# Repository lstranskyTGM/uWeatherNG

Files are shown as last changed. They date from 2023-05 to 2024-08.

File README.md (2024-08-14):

# uWeatherNG_Project

An ESP32-based weather monitoring system that collects environmental data from various sensors and publishes it to a MQTT broker topic. An agent subscribed to this topic receives the data and forwards it to an InfluxDB database. The data is then displayed on a website and visualized using Grafana dashboards.

## Background

This project was undertaken during the fourth year at TGM (Technologisches Gewerbemuseum Wien). We built upon the [project](https://github.com/lstranskyTGM/uWeather) developed in the third grade. Throughout the year, we documented our progress and presented the project's status to our teachers.

## Overview

### ESP32
- Main controller for the weather monitoring system
- Reads sensor data
- Sends data to database
- Enters DeepSleep for configured time
- Wakes up and repeats

### MQTT Broker
- Receives data from ESP32

### Telegraf
- Collects data from MQTT Broker
- Sends data to InfluxDB

### InfluxDB
- Stores data from ESP32

### Website
- Displays data from database
- Shows ESP32 location on Google Maps

### Grafana
- Visualizes data from database

### Cloudflared (Optional)

- Securely exposes local server to the internet

## Documentations

- [DockerCompose](https://github.com/lstranskyTGM/uWeatherNG/tree/main/DockerCompose)
- [ESP32](https://github.com/lstranskyTGM/uWeatherNG/tree/main/ESP32)
- [Hardware](https://github.com/lstranskyTGM/uWeatherNG/tree/main/Hardware)
- [Website](https://github.com/lstranskyTGM/uWeatherNG/tree/main/Website)

## Development

(In Progress)

## Implemented Functions

- [x] Swithed to LTE instead of WiFi
- [x] Added an Anemometer to measure wind speed
- [x] Added a Wind Vane to measure wind direction
- [x] Added an Air Quality Sensor to measure air quality
- [x] Implemented Grafana to display data from the database
- [x] Used the MQTT protocol for data transmission
- [x] Replaced the MySQL database with a InfluxDB database

## Unimplemented Functions

- [ ] Micro SD Card Reader Module (hardware implemented, code not written)

## Implemented Functions

## Possible Extensions

- [ ] Switch to LoRaWAN for extended range and cost-effective data transfer
- [ ] Add a Rain Gauge to measure rainfall
- [ ] Disable unused digital pins to conserve power when not needed
- [ ] Develop a custom PCB for the ESP32 and all sensors
- [ ] Replace the ESP32 Dev Module with a more compact and efficient ESP32 board
- [ ] Implement ESPHome / Home Assistant

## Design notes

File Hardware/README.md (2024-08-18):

# Hardware Box

<p align="center">
    
</p>

## Overview

The uWeatherNG project’s hardware components were designed using Fusion 360 and 3D printed with an Original Prusa i3 MK3S+ printer.

This system is modular and easy to set up, consisting of several key components:

**Main Parts:**

- **Main Box:** This is the heart of the system, containing the ESP32 microcontroller, OLED display, LTE and GPS modules, SD card reader, and a power bank. It handles all the data processing and transmission.

- **Sensor Box:** This box holds all the environmental sensors, keeping them safe while they collect weather data.

- **Cable Box:** A dedicated space for organizing and storing all the cables, keeping the setup tidy.

- **Anemometer and Wind Vane:** These tools measure wind speed and direction, which are key parts of weather monitoring.

- **Antenna Mount:** This part holds the antenna in place, ensuring good signal strength for data communication.

The system is built using connectors and aluminum tubes, which make it easy to assemble and disassemble, allowing for quick deployment in different locations.

**Material and Durability:** The prototype is printed with PETG filament, which is waterproof, UV-resistant, and weatherproof, making it durable for outdoor use.

**Additional Features:**

- **Air Vents:** These vents are included to allow proper airflow around the sensors, ensuring they measure accurate environmental conditions without being influenced by any potential heat build-up inside the enclosure.
  
- **Plexiglass Covers:** These protect the sensors and modules from rain, while still allowing them to function properly.
  
- **Dupont Connectors:** These are used for all the cable connections, making the setup easy to put together and take apart.

Overall, the uWeatherNG system is designed to be strong, reliable, and able to withstand different weather conditions, making it perfect for ongoing weather monitoring.

## Other Images

<table>
  <tr>
    <td align="center">
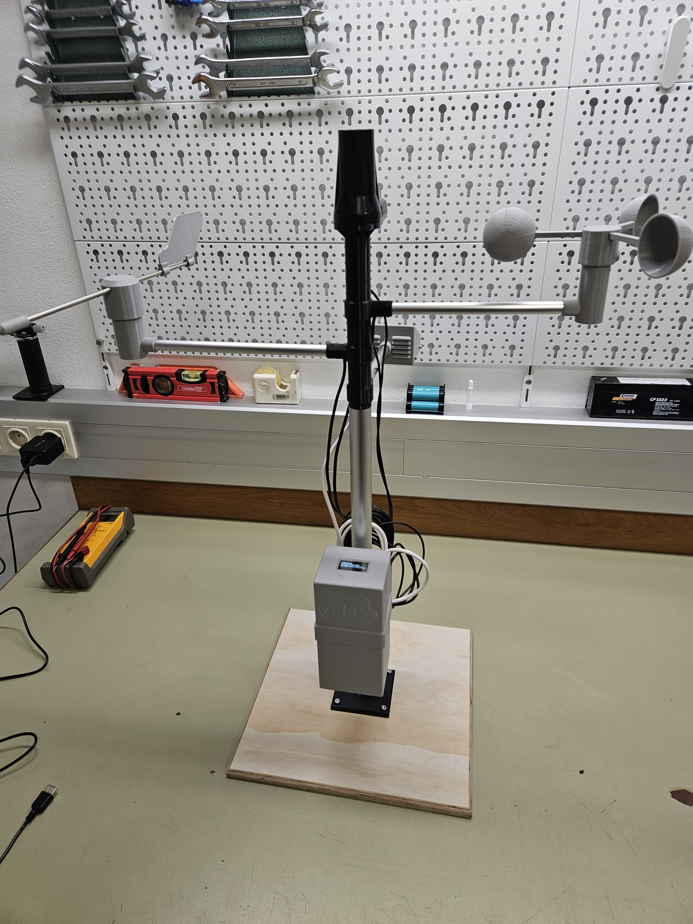
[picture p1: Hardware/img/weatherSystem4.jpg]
      
    </td>
    <td align="center">
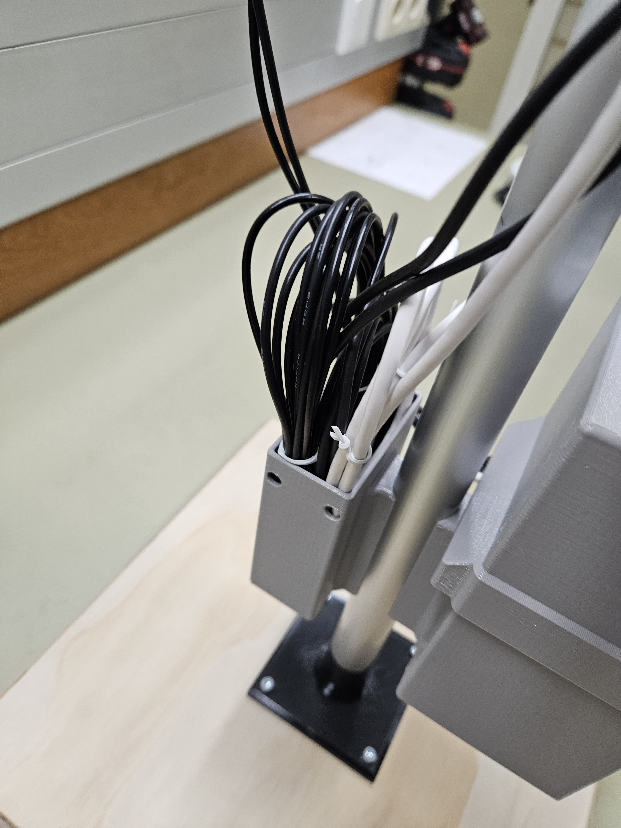
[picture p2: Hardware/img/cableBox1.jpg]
      
    </td>
    <td align="center">
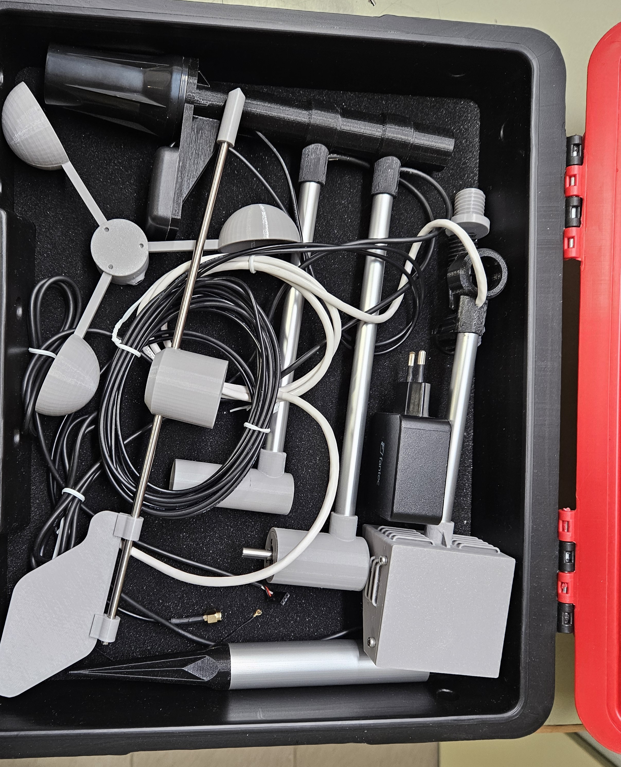
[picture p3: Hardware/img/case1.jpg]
      
    </td>
  </tr>
  <tr>
    <td align="center">
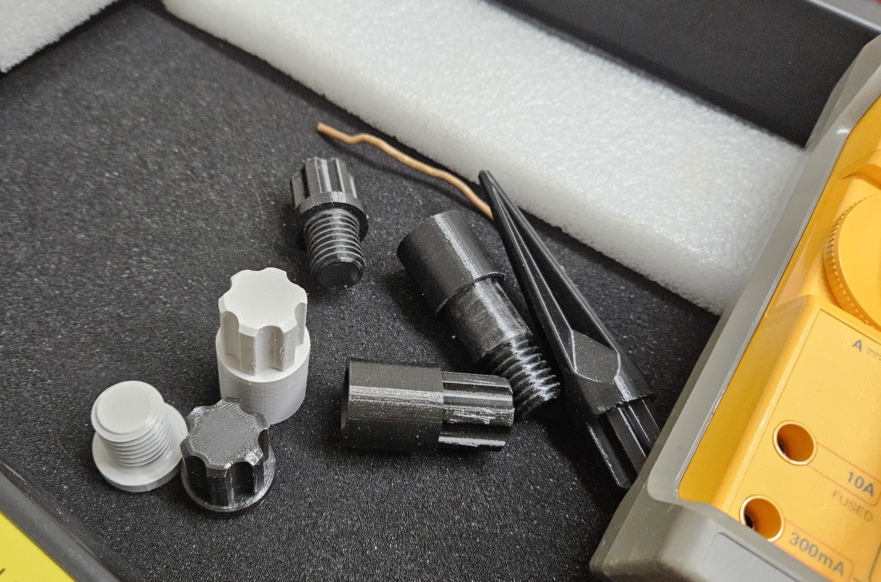
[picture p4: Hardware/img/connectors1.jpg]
      
    </td>
    <td align="center">
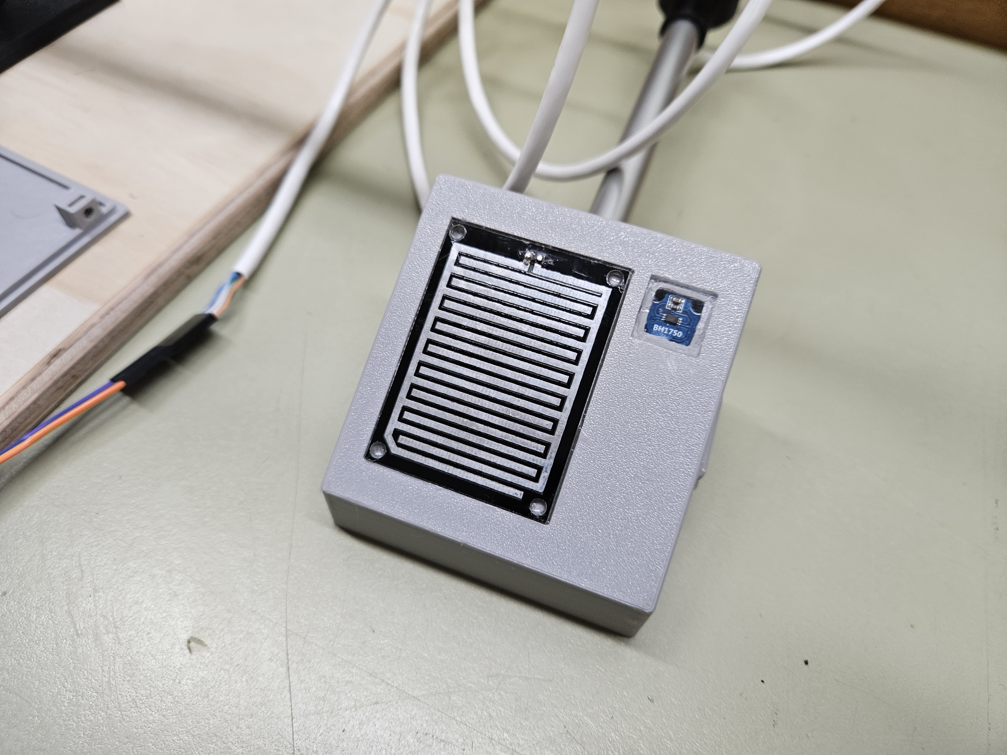
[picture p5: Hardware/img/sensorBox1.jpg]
      
    </td>
    <td align="center">
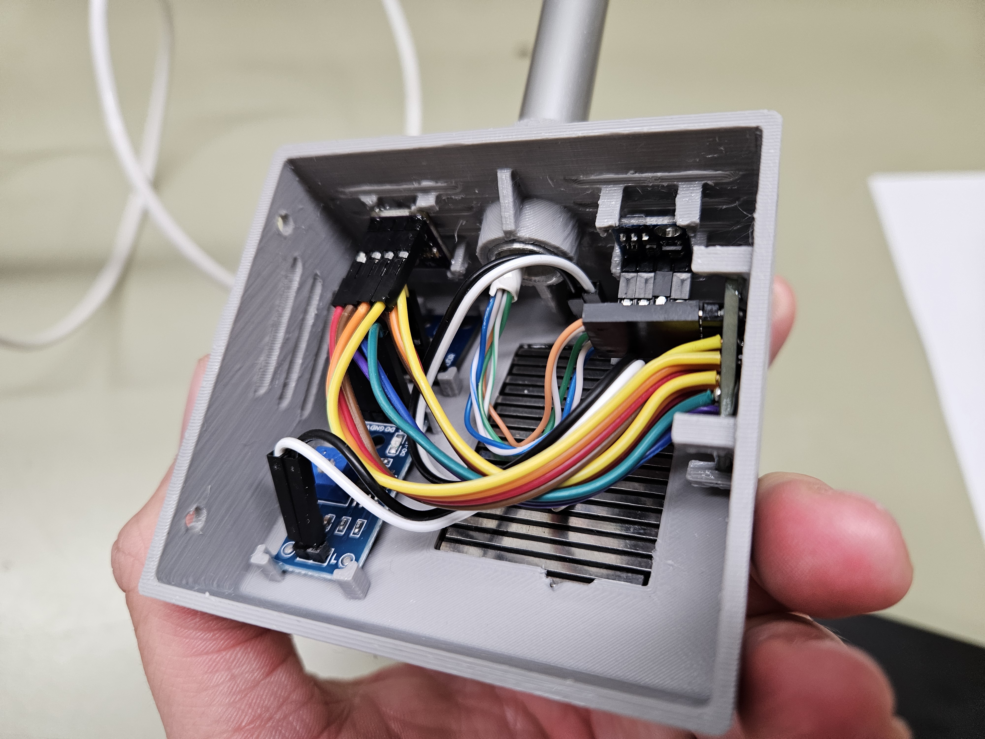
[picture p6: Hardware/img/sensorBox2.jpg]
      
    </td>
  </tr>
  <tr>
    <td align="center" colspan="3">
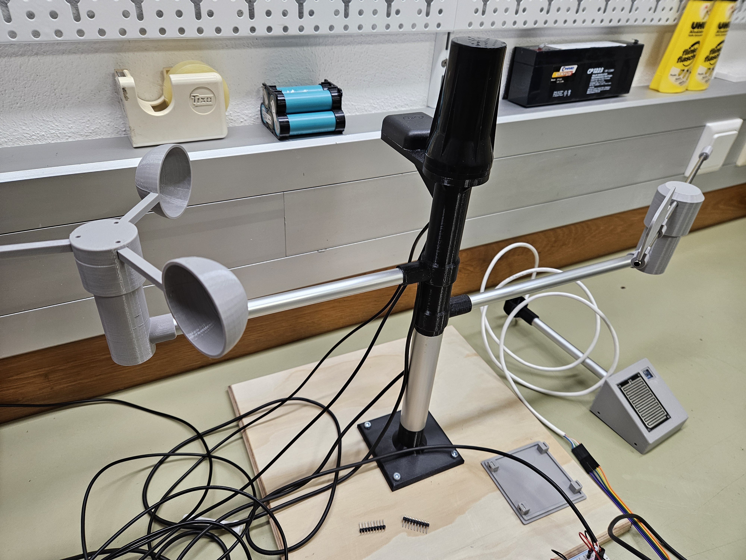
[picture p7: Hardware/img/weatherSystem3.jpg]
      
    </td>
  </tr>
</table>

## External Resources

For the anemometer and wind vane used in this project, I utilized existing models available on Thingiverse, with some modifications to better suit the needs of this project. You can find the original models I used and modified here:

- **Anemometer:** [Thingiverse Link](https://www.thingiverse.com/thing:2559929/files)
- **Wind Vane:** [Thingiverse Link](https://www.thingiverse.com/thing:4757278/files)

## ToDo

- [x] ~~Modular System~~
- [x] ~~Water resistant~~
- [x] ~~uWeather Logo~~
- [x] ~~Larger Display~~

## Possible Extensions

- [ ] Seal Connections between the parts
- [ ] MainBox Angled Top for better rain runoff

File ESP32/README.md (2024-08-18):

# ESP32

## Test Scripts

In the test scripts all functions for the ESP32 are tested seperately. This makes it easier to find errors and debug everything.   

## Main Script

<p align="center">
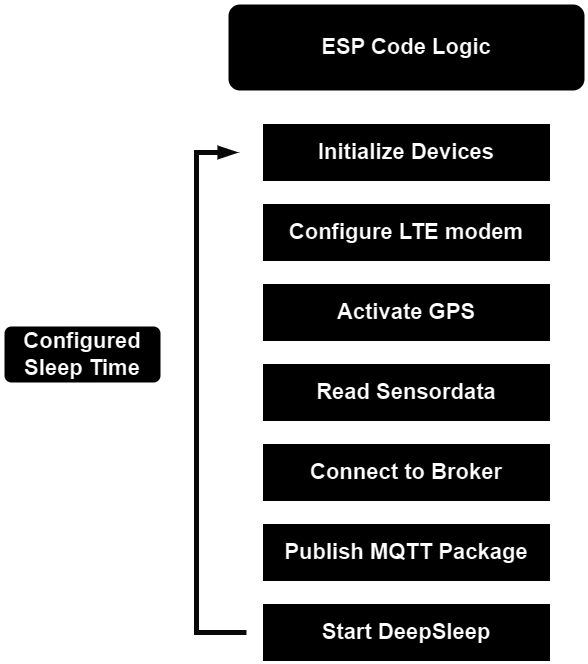
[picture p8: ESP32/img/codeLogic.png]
codeLogic
    
</p>

The ESP32 script initiates by setting up various sensors and modules, including GPS, and collecting environmental data. It then attempts to transmit this information via MQTT over an LTE connection. If the connection is established, the collected data is published to a designated topic on an MQTT broker. After transmission, the ESP32 enters a deep sleep mode to conserve energy, periodically waking to update and resend data. Throughout this process, all status updates and messages are displayed both on the Serial Monitor and an OLED display. This configuration ensures continuous, efficient monitoring of environmental conditions with minimal human intervention.

## Sensor / Module List

### GY-302 BH1750 Light Sensor Module

The GY-302 BH1750 Photoresistor module is used to measure light intensity. The resistance will decrease in the presence of light and increase in the absence of it. 

**Light Intensity:** lux

[Buy here](https://www.az-delivery.com/products/gy-302-bh1750-lichtsensor-lichtstaerke-modul-fuer-arduino-und-raspberry-pi)

### GY-BME280 Environmental Sensor [I2C]

This sensor measures relative humidity, barometric pressure, and ambient temperature, communicating via the I2C bus.

**Relative Humidity:** %RH

**Barometric Pressure:** hPa

**Ambient Temperature:** °C

[Buy here](https://www.bosch-sensortec.com/products/environmental-sensors/humidity-sensors-bme280/)

### FC-37 Rain Sensor Module

The FC-37 module detects rain, with lower resistance signaling rain presence and triggering a high output signal.

**Rain:** True/False

[Buy here](https://www.az-delivery.com/en/products/regen-sensor-modul)

### GY-SGP30 Air Quality Sensor [I2C]

THe GY-SGP30 is a digital air quality sensor that measures the amount of volatile organic compounds (VOCs) in the air. The sensor also measures the equivalent carbon-dioxide (eCO2) concentration.
It uses the I2C bus to communicate with the ESP32.

**Total Volatile Organic Compounds (TVOC):** ppb

**Equivalent Carbon-dioxide (eCO2):** ppm

[Buy here](https://funduinoshop.com/elektronische-module/sensoren/gase/gy-sgp30-tvoc-sensor-fuer-luftqualitaet-eco2)

### KY-003 Digital Hall Effect Sensor (Anemometer)

This sensor detects the magnetic field of a spinning magnet attached to an anemometer to calculate wind speed.

**Wind Speed:** km/h

[Buy here](https://www.az-delivery.com/en/products/hall-sensor-modul-digital)

### Rotary Hall Angle Sensor (Wind Vane)

The rotary hall angle sensor is used to measure the angle of the wind vane.

**Wind Direction:** Degrees (°)

[Buy here](https://www.aliexpress.com/item/4000143910873.html?gatewayAdapt=glo2deu)

### 1.3 inch OLED Display [I2C]

This OLED display shows the status and data collected by the ESP32, utilizing the I2C bus for communication.

[Buy here](https://www.az-delivery.de/en/products/1-3zoll-i2c-oled-display)

### Micro SD Card Reader Module

The micro SD card reader module is used to configure the Main Script.

[Buy here](https://www.az-delivery.de/en/products/copy-of-spi-reader-micro-speicherkartenmodul-fur-arduino)

### SIM7000E NB-IoT Module

The SIM7000E NB-IoT Module is used to connect the ESP32 to the internet, sending the data to a MQTT broker.
It also has a GPS module that can be used to get the current location of the ESP32.

**Latitude:** Degrees (°)

**Longitude:** Degrees (°)

**Altitude:** Meters (m)

[Buy here](https://www.waveshare.com/sim7000e-nb-iot-hat.htm)

## ToDo List

- [x] ~~Write all test scripts~~
- [x] ~~Write the main script~~

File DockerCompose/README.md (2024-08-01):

# DockerCompose

This system offers a ready-to-deploy solution that runs seamlessly across different environments supporting Docker and Docker Compose. It effectively orchestrates all containers, ensuring consistent performance and reliability. The setup boosts portability, scalability, and maintainability, ideal for demanding operational environments.

## Setup

1. Ensure Docker and Docker Compose are installed on your system.
2. Clone the repository to your local machine.
3. Navigate to the `DockerCompose` directory.
4. Configure the docker-compose.yml file to suit your environment.
5. Run the following command to start the system:

```bash
docker-compose up -d
```

6. Create Tokens for Grafana and Telegraf
7. Update the Telegraf configuration file with the InfluxDB token
8. Configure Grafana to connect to InfluxDB

## Configuration

### Docker Compose

Set credentials and environment variables in the `docker-compose.yml` file.

### Cloudflared (Optional)

Configure the tunnel `your-tunnel-id.json` and `config.yml` files.

### Mosquitto (Optional)

Configure the `mosquitto.conf` file with the desired settings.

### Telegraf

Configure the `telegraf.conf` file with the InfluxDB token.
If you are using the external MQTT broker change the broker address.
Change any other settings as needed. 

## Structure

The system includes the following components:

- **Cloudflared: (Optional)** A tunneling service that securely exposes the local server to the internet.
- **Mosquitto: (Optional)** An MQTT broker that enables real-time communication between IoT devices.
- **Telegraf:** A plugin-driven server agent for collecting and reporting metrics.
- **InfluxDB:** A time-series database that stores data points.
- **Grafana:** A visualization tool that creates dashboards for monitoring and analyzing data.
- **httpd:** A web server that provides access to a web page.

## Data Flow

The ESP32 device collects environmental data from various sensors and transmits it to the MQTT broker using the MQTT protocol. The data is then forwarded to the Telegraf agent, which processes and sends it to the InfluxDB database for storage. Grafana connects to the database to retrieve the data points and displays them on a dashboard for monitoring and analysis. Users can access the dashboard or a web page hosted by the httpd server to viev the real-time data.

## Line Protocol

The Line Protocol is a text-based format for writing data points to the InfluxDB database. It consists of a series of fields and tags that define the structure of the data points. The Line Protocol is used to insert, update, and delete data points in the database, enabling efficient storage and retrieval of time-series data.

### Format

````plaintext
<measurement>[,<tag-key>=<tag-value>,...] [<field-key>=<field-value>,...] [<timestamp>]
````

### Example 

```plaintext
# With Timestamp
weather,location=Vienna temperature=25,humidity=50,pressure=1013 1626825600000000000

# Without Timestamp
weather,location=Vienna temperature=25,humidity=50,pressure=1013
```

## Possible Extensions

- [ ] Add dashboard data for grafana

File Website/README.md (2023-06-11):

# Website

## Logo:

<p align="center">
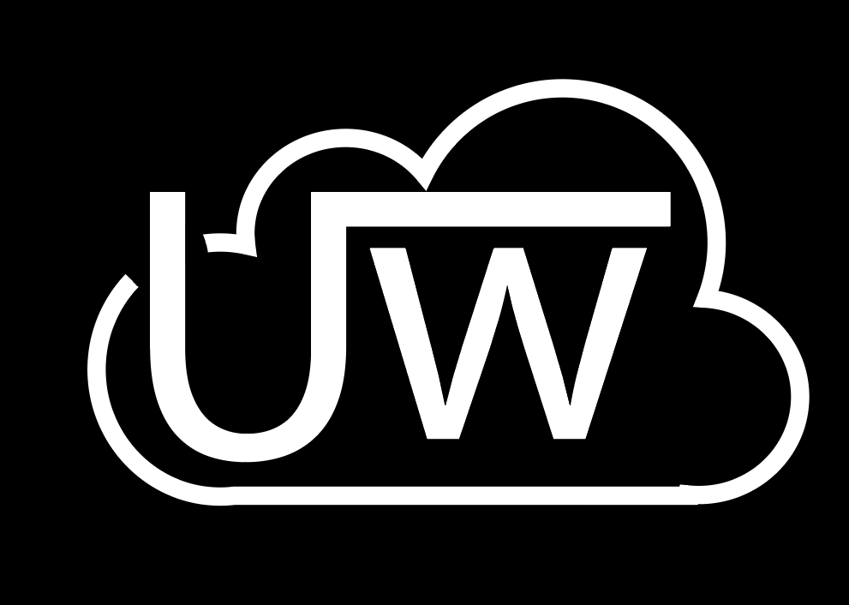
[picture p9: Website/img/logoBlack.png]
uWeather_Logo
    
</p>

## Mockup:

<p align="center">
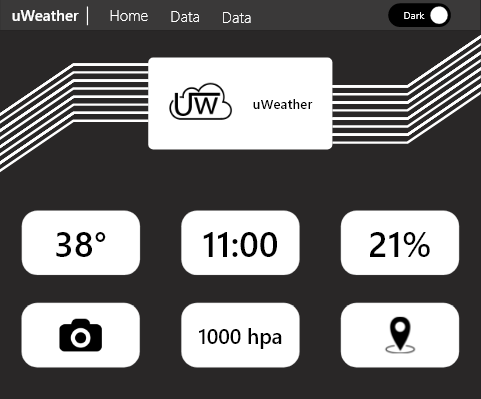
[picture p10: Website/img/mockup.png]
website_Mockup
    
</p>

The current Website displays all the sensor Data from the ESP32 and the time when the data was updated. Google Maps also shows the exact location of the ESP32 (20-30 meters inaccuracy). Animations are used to make the website more appealing. 

For an White/Dark Mode was not enough time.
The values presented on the website are only placeholders, because NodeJs/VueJs was not implemented yet.  

# ToDo List:

- [x] ~~Create a Mockup~~
- [x] ~~Create a Logo~~
- [x] ~~Create a basic html Website~~
- [x] ~~Implement css (Bootstrap)~~
- [x] ~~Implement Animations~~
- [x] ~~Implement Connection to Database~~
- [x] ~~Implement Google Maps~~
- [x] ~~Implement Bootstrap~~
- [ ] Implement White/Dark Mode
- [ ] Implement NodeJs/VueJs to Update Sensor Data

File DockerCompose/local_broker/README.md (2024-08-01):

# local_broker

This Docker Compose configuration includes a local MQTT broker, creating a self-contained system for data exchange. This setup is best suited for standalone deployments or when data sovereignty and network independence are priorities.

## Cloudflared (Optional)

This optional tunneling service securely exposes your local server to the internet via the Cloudflare network, enhancing data privacy and integrity. It can be disabled for closed-network environments to streamline operations.

## Mosquitto (Optional)

An efficient, lightweight MQTT broker that enables real-time communication between IoT devices. It is particularly useful in localized networks or for testing purposes and can be disabled if not needed.

## Telegraf

A plugin-driven server agent that collects metrics from diverse sources including system metrics, logs, and sensors. Data is forwarded to InfluxDB for detailed analysis, optimized for scalability and flexibility in data handling.

## InfluxDB

A specialized time-series database that excels in storing and retrieving structured data points efficiently. It supports complex queries and real-time analytics, making it perfect for high-velocity data environments.

## Grafana

A powerful visualization tool that creates intuitive dashboards from data stored in InfluxDB. It helps monitor system performance and identify trends, aiding in decision-making and operational oversight.

## httpd

This web server component acts as the front end, offering real-time interaction and visualization of the data through a user-friendly web interface.

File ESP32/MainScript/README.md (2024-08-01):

# MainScript

# ToDo List

- [x] ~~Implement SGP30 Sensor~~
- [x] ~~Implement Anemometer~~
- [x] ~~Implement Wind Vane~~
- [x] ~~Implement LTE Modem~~
- [x] ~~Implement MQTT Client~~
- [x] ~~Implement Read GNSS~~
- [ ] Implement Micro SD Card Reader
  
## Possible Extensions

- [ ] Implement `millis()` instead of `delay()`
- [ ] Implement startup delay to allow sensors to warm up
- [ ] Optimize power usage by controlling digital pins
- [ ] Implement local storage for data
- [ ] Implement logging file for errors
- [ ] Implement configuration file for settings

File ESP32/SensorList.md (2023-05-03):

# Sensor List:

## KY0-18:  gemacht

The KY-018 Photoresistor module is used to measure light intensity. The resistance will decrease in the presence of light and increase in the absence of it. The output is analog and determines the intensity of light.

Light intensity: lux

Link:
https://arduinomodules.info/ky-018-photoresistor-module/

## BME280: gemacht

Humidity sensor measuring relative humidity, barometric pressure and ambient temperature

Relative humidity: %

Barometric pressure: hPa

Ambient temperature: m

Link:
https://www.bosch-sensortec.com/products/environmental-sensors/humidity-sensors-bme280/

##  Raindrop Rain Sensor Module   gemacht

Raindrop Rain Sensor Module is a module used to detect and measure rain. It usually consists of a sensor that can detect the presence of water droplets, and an electronic circuit that can process the signal from the sensor and output an indication of whether it is raining or not. 

Rain: (true/false)

Link:
https://www.az-delivery.de/en/products/regen-sensor-modul

##  NEO-6M GPS Module: gemacht

GPS Sensor

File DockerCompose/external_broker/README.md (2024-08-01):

# external_broker

This Docker Compose configuration is designed for integration with an external MQTT broker, facilitating seamless data exchange with existing infrastructures and services. This setup is ideal for environments where centralized control over multiple deployments is needed.

## Cloudflared (Optional)

This optional tunneling service securely exposes your local server to the internet via the Cloudflare network, enhancing data privacy and integrity. It can be disabled for closed-network environments to streamline operations.

## Telegraf

A plugin-driven server agent that collects metrics from diverse sources including system metrics, logs, and sensors. Data is forwarded to InfluxDB for detailed analysis, optimized for scalability and flexibility in data handling.

## InfluxDB

A specialized time-series database that excels in storing and retrieving structured data points efficiently. It supports complex queries and real-time analytics, making it perfect for high-velocity data environments.

## Grafana

A powerful visualization tool that creates intuitive dashboards from data stored in InfluxDB. It helps monitor system performance and identify trends, aiding in decision-making and operational oversight.

## httpd

This web server component acts as the front end, offering real-time interaction and visualization of the data through a user-friendly web interface.

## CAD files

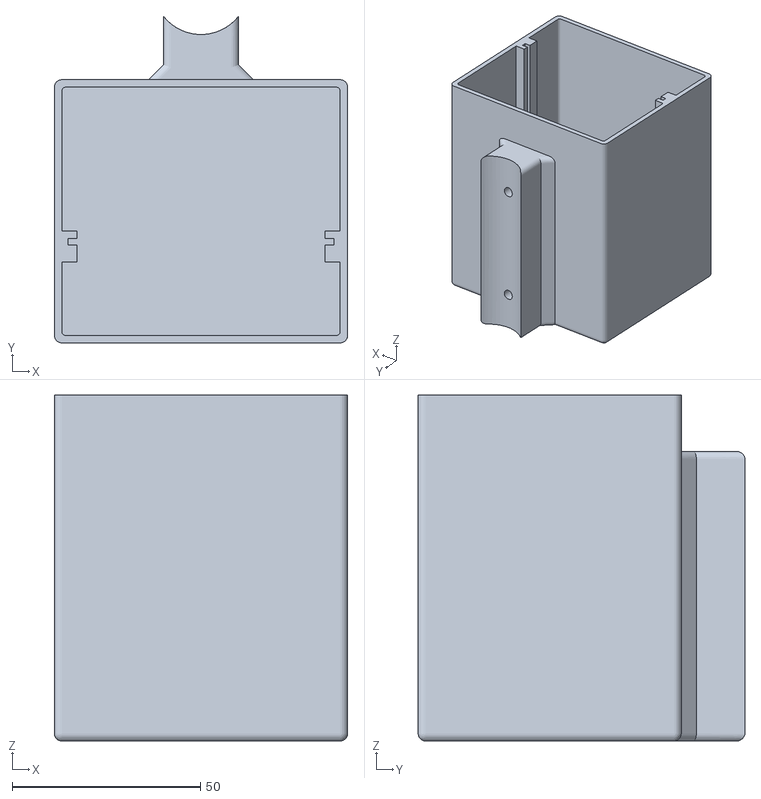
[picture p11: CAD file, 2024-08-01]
Hardware/MainBox/MainBox_Bottom.stl
78.0 x 86.9 x 92.0

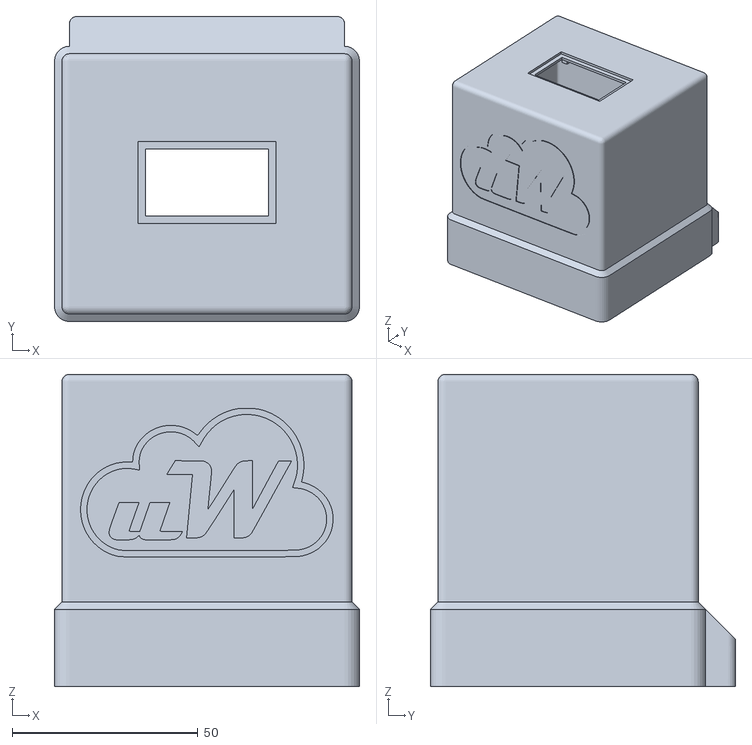
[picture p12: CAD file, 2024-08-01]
Hardware/MainBox/MainBox_Top.stl
82.0 x 82.0 x 84.0

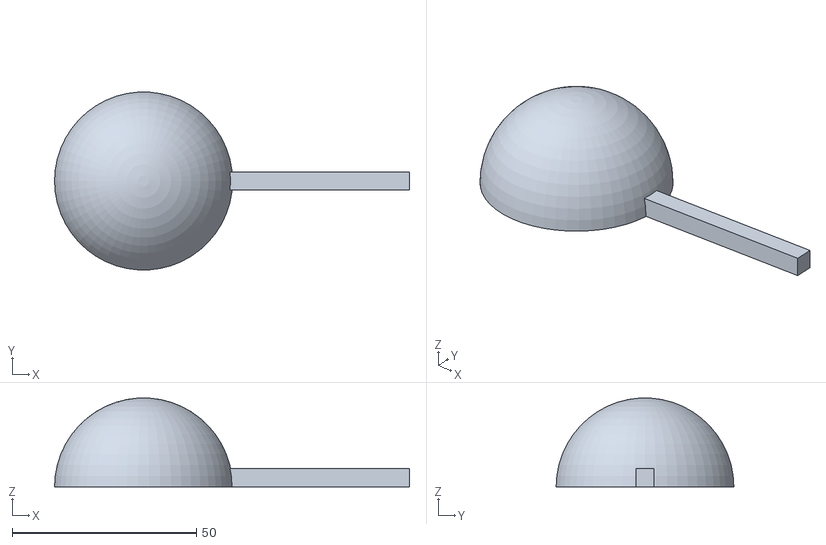
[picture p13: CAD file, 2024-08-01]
Hardware/Anemometer/Anemometer_Cup.stl
96.3 x 48.2 x 24.1

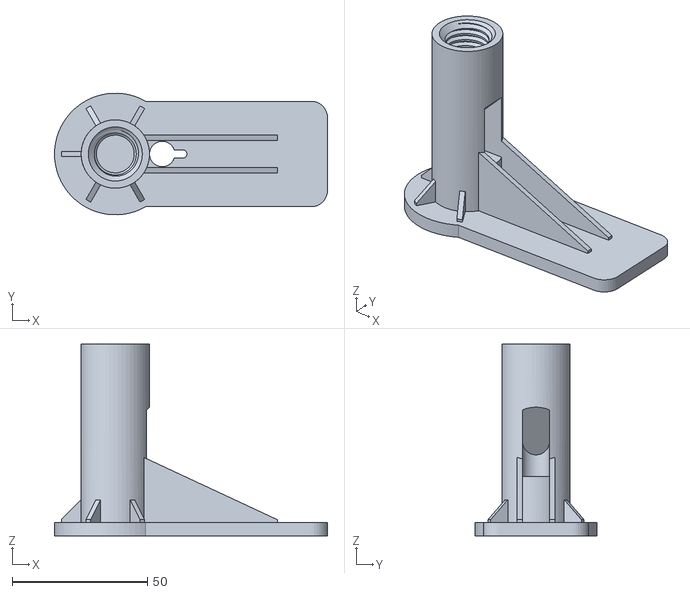
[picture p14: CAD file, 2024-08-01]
Hardware/Antenna/AntennaHolder_InternalThread.stl
101.0 x 45.0 x 71.0

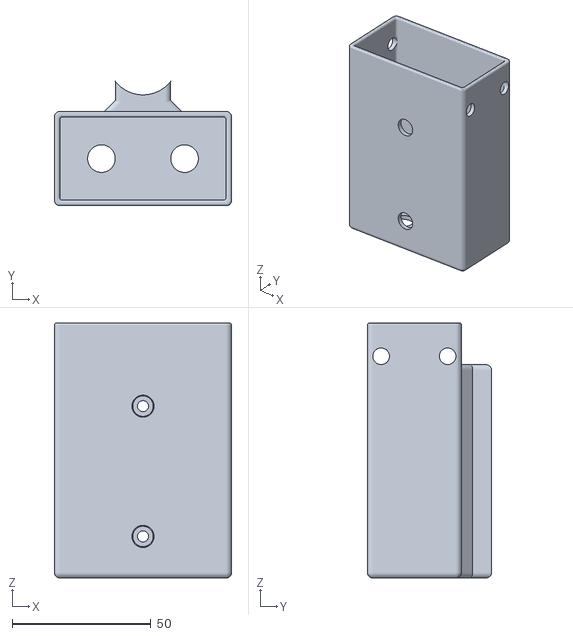
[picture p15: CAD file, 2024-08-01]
Hardware/CableManagement/CableBox.stl
64.0 x 44.9 x 92.0

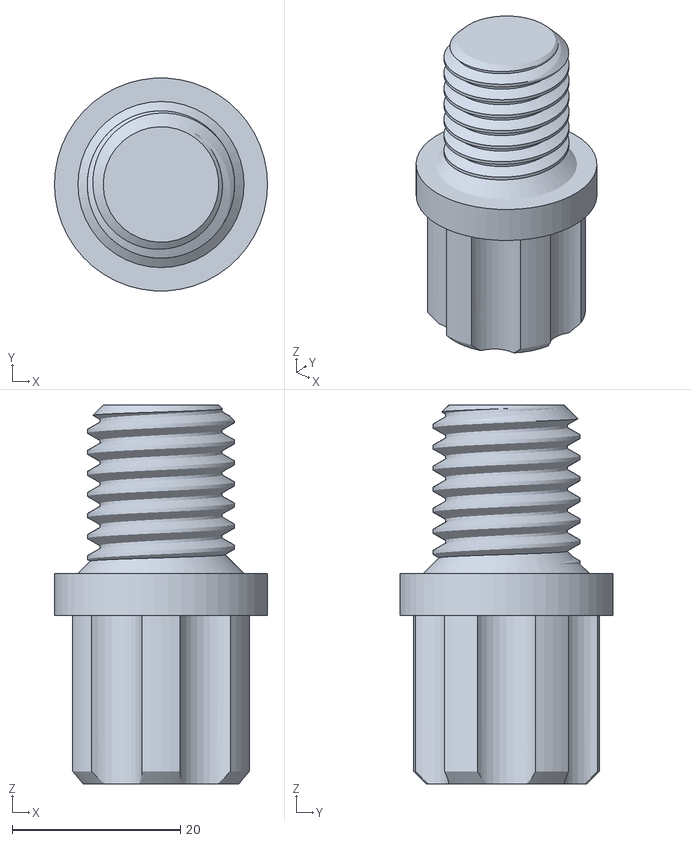
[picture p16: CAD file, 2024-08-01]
Hardware/Connectors/Plug_ExternalThread.stl
25.3 x 25.3 x 45.0

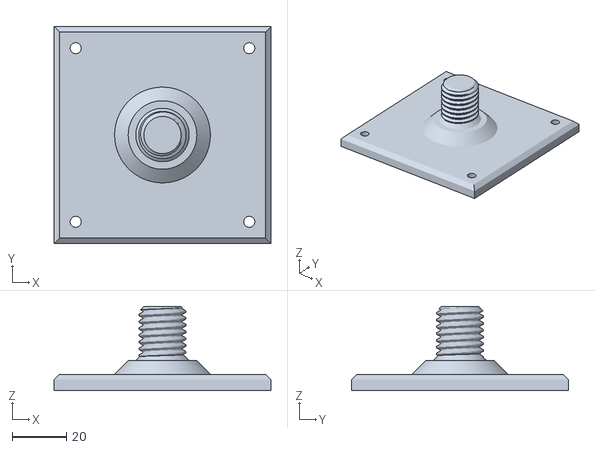
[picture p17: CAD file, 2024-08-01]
Hardware/MountingPlates/Plate_ExternalThread.stl
80.0 x 80.0 x 31.0

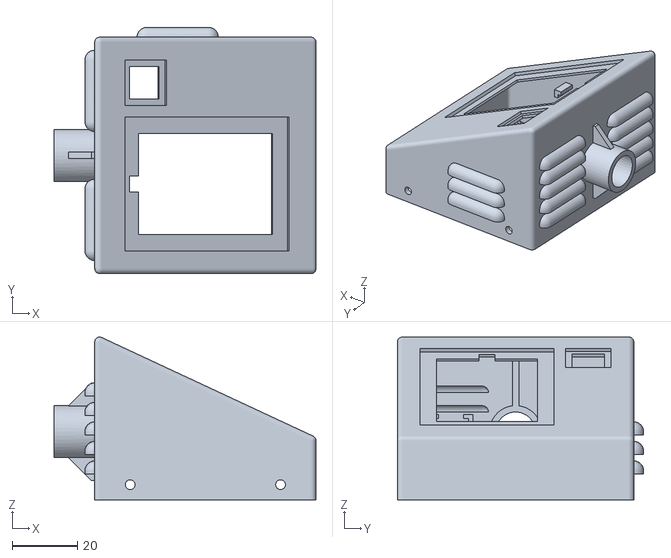
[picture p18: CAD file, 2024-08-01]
Hardware/SensorBox/SensorBox_Top.stl
80.5 x 75.6 x 50.1

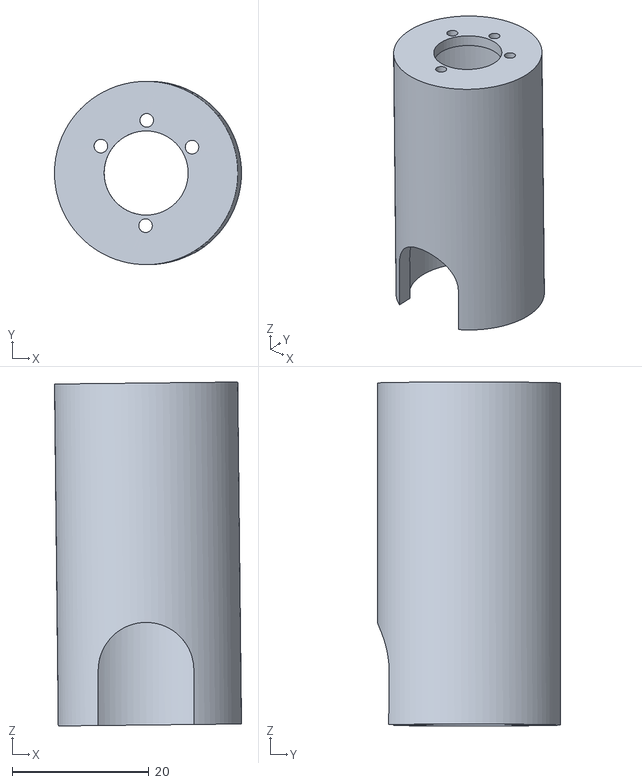
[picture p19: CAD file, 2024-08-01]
Hardware/Vane/Vane_Middle.stl
27.4 x 26.8 x 50.3

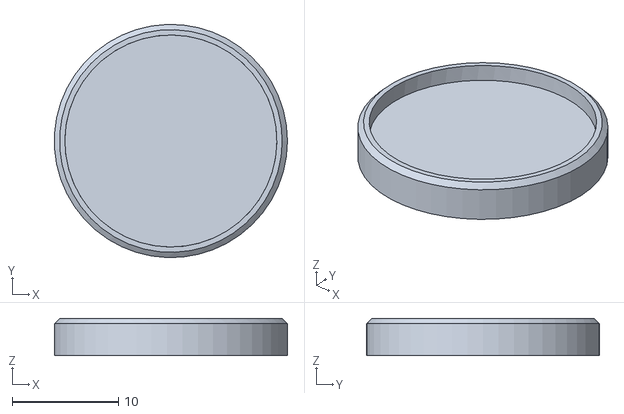
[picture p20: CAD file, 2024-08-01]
Hardware/Anemometer/Anemometer_Cap.stl
22.0 x 22.0 x 3.50

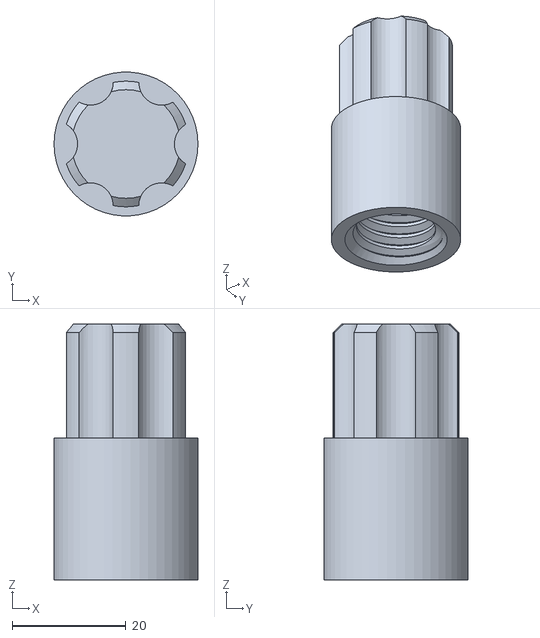
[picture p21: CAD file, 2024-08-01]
Hardware/Connectors/Plug_InternalThread.stl
25.3 x 25.3 x 45.0

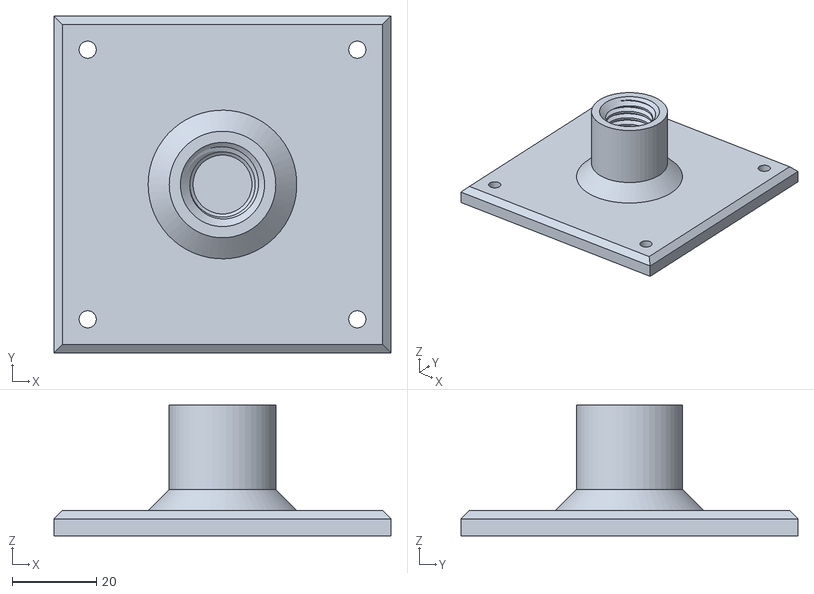
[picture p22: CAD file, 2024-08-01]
Hardware/MountingPlates/Plate_InternalThread.stl
80.0 x 80.0 x 31.0

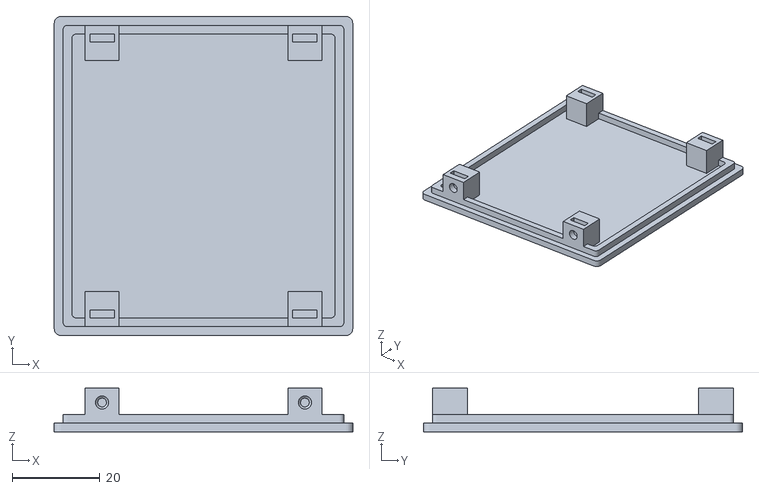
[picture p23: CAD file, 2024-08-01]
Hardware/SensorBox/SensorBox_Bottom.stl
68.0 x 72.6 x 10.0

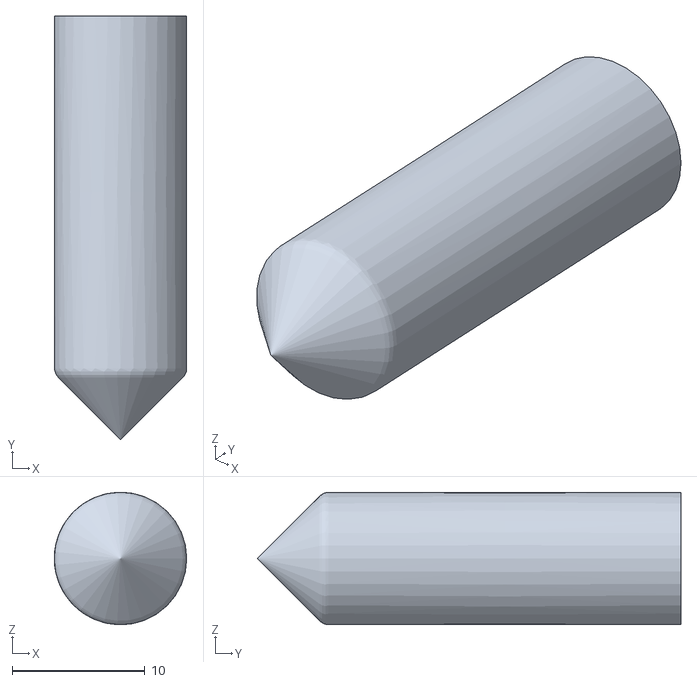
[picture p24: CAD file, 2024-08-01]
Hardware/Vane/Vane_Tip.stl
10.0 x 32.0 x 10.0

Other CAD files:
Hardware/Anemometer/Anemometer_Top.stl
Hardware/Connectors/Plug_Joint_ExternalThread.stl
Hardware/Vane/Vane_Fin.stl
Hardware/Anemometer/Anemometer_Body.stl
Hardware/Connectors/Joint.stl
Hardware/Connectors/Joint_InternalThread_ExternalThread.stl
Hardware/Connectors/Plug_Spike.stl
Hardware/Vane/Vane_Bottom.stl
Hardware/Vane/Vane_Fin_Mount.stl
Hardware/Vane/Vane_Top.stl

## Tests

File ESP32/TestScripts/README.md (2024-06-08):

# Testscripts

# ToDo List

- [x] ~~Buy Sensors~~
- [x] ~~Write scripts~~
- [x] ~~Check for errors~~

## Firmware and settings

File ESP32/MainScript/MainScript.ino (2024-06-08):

/*
 * Projekt: uWeather Datalogging System
 * Description: Utilizes ESP32 to measure environmental data with various sensors, transmitting results via MQTT. 
 * Optimized for low-power consumption with automated deep sleep cycles.
 * Author: Leonhard Stransky
 * Creation Date: 2023.05.07
 */

// Libraries
#include <time.h>                       // Standard C library for time-related functions
#include <Wire.h>                       // Wire Library for I2C communication, part of the Arduino core
#include <BH1750.h>                     // Ambient light sensor library, source: https://github.com/claws/BH1750
#include <Adafruit_Sensor.h>            // Adafruit Unified Sensor Driver, source: https://github.com/adafruit/Adafruit_Sensor
#include <Adafruit_BME280.h>            // Adafruit library for BME280 sensors, source: https://github.com/adafruit/Adafruit_BME280_Library
#include <Adafruit_SGP30.h>             // Adafruit library for the SGP30 gas sensor, source: https://github.com/adafruit/Adafruit_SGP30
#include <Adafruit_GFX.h>               // Base library for Adafruit’s display drivers, source: https://github.com/adafruit/Adafruit-GFX-Library
#include <Adafruit_SH110X.h>            // Adafruit library for SH110x Monochrome OLED/LED Displays, source: https://github.com/adafruit/Adafruit_SH110X
#include <HardwareSerial.h>             // Provides Serial communication functionality on ESP32
#include <BotleticsSIM7000.h>           // Botletics SIM7000 LTE module library, source: https://github.com/botletics/SIM7000-LTE-Shield

// LTE modem details
#define SIMCOM_7000     // LTE Module Chip
#define TX 16           // ESP32 hardware serial RX2 (GPIO16)
#define RX 17           // ESP32 hardware serial TX2 (GPIO17)

// MQTT Broker details
#define MQTT_SERVER      "mqtt.broker.net"      // The address of the MQTT broker server
// Common MQTT Ports:
// 1883: Default unencrypted port
// 8883: Default encrypted port (TLS/SSL)
// 1884: MQTT over WebSockets (unencrypted)
// 8884: MQTT over WebSockets (encrypted)
#define MQTT_PORT        1883                   // The port of the MQTT broker server
#define MQTT_USERNAME    "YourMQTTUsername"     // Optional: Username for MQTT broker authentication, if required
#define MQTT_PASSWORD    "YourMQTTPassword"     // Optional: Password for MQTT broker authentication, if required
#define MQTT_CLIENTID    "YourClientID"         // Optional: A unique client identifier used to identify the device to the broker

// Other Settings

// Boolean flag indicating whether MQTT messages should be retained on the broker
// Retain messages are stored on the broker and sent to new subscribers when they subscribe to a topic
// If set to 0 (false), messages are not retained, not stored on the broker after delivery
// If set to 1 (true), messages are retained, stored on the broker and sends them to new subscribers
const bool retain_messages = 0;

// Quality of Service (QoS) level for MQTT messages
// QoS 0: The broker/client will deliver the message once, with no confirmation
// QoS 1: The broker/client will deliver the message at least once, with confirmation required
// QoS 2: The broker/client will deliver the message exactly once by using a four-step handshake
// This setting specifies a QoS level of 2, ensuring that messages are delivered exactly once
const int qos_level = 2;

// MQTT Topics
// Topic under which sensor data will be published.
const char* topicSensors = "sensors/";

// For ESP32 hardware serial
HardwareSerial modemSS(1);                            // Instance of the HardwareSerial class to manage serial communication
Botletics_modem_LTE modem = Botletics_modem_LTE();    // Instance of the LTE modem class

// Declarations for DeepSleep
#define uS_TO_S_FACTOR 1000000ULL   // Conversion factor for micro seconds to seconds
#define TIME_TO_SLEEP 5 * 60        // Time ESP32 will go to sleep (in seconds)

// Variables that get saved during DeepSleep
RTC_DATA_ATTR int bootCount = 0;                  // Counts the number of boots since last power cycle
//RTC_DATA_ATTR boolean requestedNTP;               // If NTP Server was already requested
RTC_DATA_ATTR boolean bIsRaining = false;         // Last Known Rain Value for next boot (Inital state not raining)

// Declarations for Display
#define SCREEN_WIDTH 128        // OLED display width in pixels
#define SCREEN_HEIGHT 64        // OLED display height in pixels
#define OLED_RESET     -1       // Reset pin for the OLED Display (-1 if not used)
//#define SCREEN_ADDRESS 0x3c     // Address 0x3D for 128x64
#define WHITE 1                 // Color definition for drawing text and graphics on the display
Adafruit_SH1106G display = Adafruit_SH1106G(SCREEN_WIDTH, SCREEN_HEIGHT, &Wire, OLED_RESET);    // OLED display instance

// Declarations for OLED console buffer
String textLines[8] = {""};     // Buffer to hold up lines of text for OLED display output
int curLine=0;                  // Current line index in the buffer

// Sensors/Modules
// Sensor Object Declerations
BH1750 lightMeter;      // BH1750 Light Level Sensor (Lightlevel[lux])
Adafruit_BME280 bme;    // BME280 Sensor (Temperature[°C], Humidity[%RH"], Pressure[hPa])
Adafruit_SGP30 sgp;     // SGP30 Air Quality Sensor (TVOC[ppb], CO2[ppm])

// Pin Definitions
#define RAIN_ANALOG_PIN 32              // Rain Sensor Analog Pin (Rain[True/False])
#define WIND_SPEED_DIGITAL_PIN 35       // KY-003 Hall Sensor Digital Pin (WindSpeed[km/h])
#define WIND_DIRECTION_ANALOG_PIN 33    // Rotary Hall Angle Sensor Analog Pin (WindDirection[0-360°])

// Other variables
volatile int rotationCount = 0;                // Counts Rotations (volatile for interrupts)
unsigned long measurementDuration = 10000;     // Measurement duration in milliseconds (10 seconds)
bool initalizedLTE = false;                    // If the LTE modem was successfully initialized

// Defining Sensor Data Struct
struct SensorData {
    // Location Data
    float latitude;         // Latitude coordinate of the sensor's location
    float longitude;        // Longitude coordinate of the sensor's location
    float altitude;         // Altitude in meters above sea level

    // Weather Data
    float temperature;      // Ambient temperature measured in degrees Celsius
    float pressure;         // Atmospheric pressure measured in hectoPascals (hPa)
    float humidity;         // Relative humidity measured in percent (%)
    bool rain;              // Presence of rain: true if raining, false otherwise

    // Other Environmental Data
    float lightLevel;       // Ambient light level measured in lux
    float windSpeed;        // Wind speed measured in kilometers per hour (km/h)
    int windDirection;      // Wind direction measured in degrees from true north

    // Air Quality Data
    unsigned int tvoc;      // Total Volatile Organic Compounds measured in parts per billion (ppb)
    unsigned int eco2;      // Equivalent CO2 measured in parts per million (ppm)
};

// Defining GPS Data Struct
struct GPSData {
    float latitude;         // Latitude in decimal degrees
    float longitude;        // Longitude in decimal degrees
    float altitude;         // Altitude in meters above sea level
    bool valid;             // Validity of the GPS data
};

// WeatherStation ID
static const int WeatherStationID  = 101;    // Unique identifier for this weather station

/**
 * Setup function: Initializes components, manages data transmission, and configures deep sleep settings.
 */
void setup() {
  Serial.begin(115200);

  // Initalize Display first to show status messages
  initializeSH1106G();
  printLogo();
  delay(2000);

  // Increment boot count on each restart
  ++bootCount;
  printStatus("BootCount: " + String(bootCount));

  // Initalize all other Sensors or Modules
  initializeDevices();

  // Turn on GPS at first boot or if no GPS fix is detected
  if (bootCount == 1 || getGPSStatus() == 0) {
    toggleGPS(true);
  }
  // Implement check if there is still no fix after a long time

  // Read sensor data and publish it via MQTT
  SensorData data = readSensors();
  if (initalizedLTE) {
    printStatus("Publishing data...");
    mqttPublish(data);
  } else {
    printStatus("Failed to publish data (no LTE modem)");
  }

  // Configure and start deep sleep to save power
  configureDeepSleep(TIME_TO_SLEEP * uS_TO_S_FACTOR);
  startDeepSleep();
}

void loop() {
  // Not executed because the device enters deep sleep after setup
}

// Initialization Functions

/**
 * Initializes all connected sensors and modules.
 * Starts the I2C bus and configures each device for operation.
 */
void initializeDevices() {
  // Start i2c bus
  Wire.begin();

  // Initialize individual sensors and modules
  //initializeSH1106G();
  initalizedLTE = initializeLTEModem();
  initializeBH1750();
  initializeBME280();
  initializeRain();
  initializeSGP30();
  initializeRotaryHall();
  initializeHall();
}

/**
 * Initializes the SH1106G OLED display.
 * @return True if device is successfully initialized, false otherwise.
 */
bool initializeSH1106G() {
  if (display.begin(0x3c, true)) { 
    Serial.println("SH1106G allocation successfull");
    return true;
  } else {
    Serial.println("SH1106G allocation failed - check wiring");
    return false;
  }
}

/**
 * Initializes the LTE modem
 * @return True if device is successfully initialized, false otherwise.
 */
bool initializeLTEModem() {
  printStatus("Initializing LTE modem...(May take several seconds)");

  // SIM7000 takes about 3s to turn on and SIM7500 takes about 15s
  // Press reset button if the module is still turning on and the board doesn't find it.
  // When the module is on it should communicate right after pressing reset

  // Start at default SIM7000 shield baud rate
  //modemSS.begin(115200, SERIAL_8N1, TX, RX); // baud rate, protocol, ESP32 RX pin, ESP32 TX pin

  printStatus("Configuring to 9600 baud");
  modemSS.println("AT+IPR=9600"); // Set baud rate
  delay(100); // Short pause to let the command run
  modemSS.begin(9600, SERIAL_8N1, TX, RX); // Switch to 9600

  // Check if modem is available
  if (! modem.begin(modemSS)) {
    printStatus("LTE modem not found - check wiring");
    return false;
  } else {
    printStatus("LTE modem initialized");
  }

  // Check type
  uint8_t type = modem.type();
  printStatus("Modem is OK");
  printStatus("Found ");
  switch (type) {
    case SIM7000:
      printStatus("SIM7000"); 
      break;
    default:
      printStatus("Unknown"); 
      break;
  }

  // Print module IMEI number.
  char imei[16] = {0}; // MUST use a 16 character buffer for IMEI!
  uint8_t imeiLen = modem.getIMEI(imei);
  if (imeiLen > 0) {
    printStatus("Module IMEI: " + String(imei));
  } else {
    printStatus("Failed to retrive IMEI");
  }

  // Set modem to full functionality
  modem.setFunctionality(1); // AT+CFUN=1

  modem.setNetworkSettings(F("webLGaut")); // For HoT IoT Simcard

  return true;
}

/**
 * Initializes the BH1750 (light meter)
 * @return True if device is successfully initialized, false otherwise.
 */
bool initializeBH1750() {
  lightMeter.begin(BH1750::CONTINUOUS_HIGH_RES_MODE, 0x23);
  float lux = lightMeter.readLightLevel();
  if (lux != 0.0) { // Zero lux reading
    printStatus("BH1750 initialized");
    return true;
  } else {
    printStatus("BH1750 zero lux detected - check wiring.");
    return false;
  }
}

/**
 * Initializes the BME280 (temperature, humidity, pressure)
 * @return True if device is successfully initialized, false otherwise.
 */
bool initializeBME280() {
  if (bme.begin(0x76)) {
    printStatus("BME280 initialized");
    return true;
  } else {
    printStatus("BME280 not found - check wiring.");
    return false;
  }
}

/**
 * Initializes the FC-37 (rain)
 * @return True if device is successfully initialized, false otherwise.
 */
bool initializeRain() {
  pinMode(RAIN_ANALOG_PIN, INPUT);
  int rainValue = analogRead(RAIN_ANALOG_PIN);
    if (rainValue >= 0 && rainValue <= 4095) {
      printStatus("Rain initialized");
      return true;
    } else {
      printStatus("Rain not found - check wiring");
      return false;
    }
}

/**
 * Initializes the SGP30 (air quality)
 * @return True if device is successfully initialized, false otherwise.
 */
bool initializeSGP30() {
  if (!sgp.begin()){
    printStatus("SGP30 not found - check wiring");
    return false;
  } else {
    printStatus("SGP30 initialized");
    Serial.print("Found SGP30 serial #");
    Serial.print(sgp.serialnumber[0], HEX);
    Serial.print(sgp.serialnumber[1], HEX);
    Serial.println(sgp.serialnumber[2], HEX);

    /*
    // Humidity compensation
    sgp.setHumidity(getAbsoluteHumidity(bme.readTemperature(), bme.readHumidity()));

    // Update Baseline values
    if (bootCount % 30 == 0) {
      uint16_t TVOC_base, eCO2_base;
      if (sgp.getIAQBaseline(&eCO2_base, &TVOC_base)) {
        printStatus("Baseline eCO2: 0x" + String(eCO2_base, HEX));
        printStatus("Baseline TVOC: 0x" + String(TVOC_base, HEX));
      } else {
        printStatus("Failed to get baseline readings");
      }
    }
    */

    return true;
  }
}

/**
 * Initializes the anemometer (wind speed)
 * @return True if device is successfully initialized, false otherwise.
 */
bool initializeHall() {
  pinMode(WIND_SPEED_DIGITAL_PIN, INPUT);
  if (true) {   // Add check
    printStatus("KY-003 Hall initialized");
    return true;
  } else {
    printStatus("KY-003 Hall not found - check wiring");
    return false;
  }
}

/**
 * Initializes the wind vane (wind direction)
 * @return True if device is successfully initialized, false otherwise.
 */
bool initializeRotaryHall() {
//  pinMode(WIND_DIRECTION_ANALOG_PIN, OUTPUT);
  pinMode(WIND_DIRECTION_ANALOG_PIN, INPUT);
  int sensorValue = analogRead(WIND_DIRECTION_ANALOG_PIN);
  if (sensorValue >= 0 && sensorValue <= 1437) {   // Add check
    printStatus("Rotary Hall initialized");
    return true;
  } else {
    printStatus("Rotary Hall not found - check wiring");
    return false;
  }
}

// Data Functions

/**
 * Reads and aggregates data from environmental sensors into a structured format.
 * @return SensorData struct containing all the sensor readings.
 */
SensorData readSensors() {
  // Create struct
  SensorData data;

  printStatus("Reading sensor data..");

  // Read lightlevel (BH1750)
  data.lightLevel = lightMeter.readLightLevel();
  printStatus("LightLevel="+String(data.lightLevel)+"lux");

  // Read temperature, pressure, and humidity (BME280)
  data.temperature = bme.readTemperature();
  data.pressure = bme.readPressure() / 100.0F;
  data.humidity = bme.readHumidity();
  printStatus("Temperature="+String(data.temperature)+"degC");
  printStatus("Pressure="+String(data.pressure)+"hPa");
  printStatus("Humidity="+String(data.humidity)+"%RH");

  // Read rain status (FC-37)
  data.rain = measureRain();
  printStatus(data.rain ? "Raining=TRUE" : "Raining=FALSE");

  // Read air quality (SGP30)
  data.tvoc = sgp.TVOC;
  data.eco2 = sgp.eCO2; 
//  unsigned int rawH2 = sgp.rawH2;
//  unsigned int rawEthanol = sgp.rawEthanol;
  printStatus("TVOC="+String(data.tvoc)+"ppb");
  printStatus("eC02="+String(data.eco2)+"ppm");
//  printStatus("rawH2="+String(rawH2));
//  printStatus("rawEthanol="+String(rawEthanol));

  // Read wind speed (KY-003)
  data.windSpeed = measureWindSpeed();
  printStatus("WindSpeed="+String(data.windSpeed)+"km/h");

  // Read wind direction
  uint16_t windDirAnalog = analogRead(WIND_DIRECTION_ANALOG_PIN);
//  data.windDirection = map(windDirAnalog, 0, 3120, 0, 359);
  if (windDirAnalog > 3120) {
    data.windDirection = 0;
  } else {
    // 360 / 3120 (Max Value) = 0.115
    data.windDirection = windDirAnalog * 0.115;
  }
  printStatus("WindDirectionAnalog="+String(windDirAnalog));
  printStatus("WindDirection="+String(data.windDirection)+"deg");

  // Fetch GPS data if a valid fix is available
  GPSData gpsData = getGPSData();
  if (gpsData.valid) {
    data.latitude = gpsData.latitude;
    data.longitude = gpsData.longitude;
    data.altitude = gpsData.altitude;
  }

  return data;
}

/**
 * Checks the rain sensor's analog value to determine if it is raining.
 * Updates the `bIsRaining` status based on threshold values:
 * - Sets `bIsRaining` to true if the reading is below 2700.
 * - Sets `bIsRaining` to false if the reading is above 3400.
 * @return bool - True if raining, false otherwise.
 */
bool measureRain() {
  int rainAnalogVal = analogRead(RAIN_ANALOG_PIN);
  printStatus("rainAnalog="+String(rainAnalogVal));
  if (!bIsRaining && rainAnalogVal < 2500) {
    bIsRaining = true;
  } else if (bIsRaining && rainAnalogVal > 3000) {
    bIsRaining = false;
  }
  return bIsRaining;
}

/**
 * Measures wind speed by counting rotations detected by the KY-003 Hall sensor.
 * The function attaches an interrupt to the sensor, counts rotations for a fixed duration,
 * and then calculates the wind speed based on the number of rotations.
 * @return The calculated wind speed in meters per second.
 */
float measureWindSpeed() {
  unsigned long startMillis = millis(); // Record start time
  unsigned long currentMillis;
  rotationCount = 0; // Reset rotation count at the beginning

  // Attach interrupt to count rotations
  attachInterrupt(digitalPinToInterrupt(WIND_SPEED_DIGITAL_PIN), countRotation, RISING);

  // Loop until measurementDuration passes
  do {
    currentMillis = millis(); // Update current time
  } while (currentMillis - startMillis < measurementDuration);

  // Detach the interrupt to stop counting
  detachInterrupt(digitalPinToInterrupt(WIND_SPEED_DIGITAL_PIN));

  printStatus("rotationCount=" + String(rotationCount));

  // Calculate the wind speed
  return calculateWindSpeed(rotationCount);
} 

// Network Functions

/**
 * Publishes collected sensor data to an MQTT broker using specified settings.
 * Constructs and sends a data payload formatted according to the InfluxDB Line Protocol.
 * @param data The SensorData struct containing environmental readings to be published.
 */
void mqttPublish(SensorData data) {
  // Establish a wireless connection
  modem.openWirelessConnection(true);

  // Configure MQTT settings for connection
  modem.MQTT_setParameter("URL", MQTT_SERVER, MQTT_PORT);
  // Optional settings
  modem.MQTT_setParameter("USERNAME", MQTT_USERNAME);
  modem.MQTT_setParameter("PASSWORD", MQTT_PASSWORD);
  modem.MQTT_setParameter("CLIENTID", MQTT_CLIENTID);

  printStatus("Connecting to MQTT broker...");
  if (! modem.MQTT_connect(true)) {
    printStatus("MQTT broker connect failed");
    // Closes connection on failure
    modem.openWirelessConnection(false);
    return;
  } else { 
    printStatus("MQTT broker connected");
  }

  // Getting current time as Unix timestamp
//  time_t now;
//  time(&now);  // Get the current time as a time_t object

  // Configure the topic string with the station ID
  String topic = String(topicSensors) + String(WeatherStationID);

  // Add checks for building Line Protocol

  // Build the payload in InfluxDB Line Protocol format
  String lineProtocol = "weather,stationID=" + String(WeatherStationID) + " ";

  if (!(data.latitude == 0 && data.longitude == 0 && data.altitude == 0)) {
    lineProtocol += String("latitude=") + data.latitude + ","
                  + String("longitude=") + data.longitude + ","
                  + String("altitude=") + data.altitude + ",";
  }
  lineProtocol += String("temperature=") + data.temperature + ","
                + String("pressure=") + data.pressure + ","
                + String("humidity=") + data.humidity + ","
                + String("rain=") + (data.rain ? "true" : "false") + ","
                + String("lightLevel=") + data.lightLevel + ","
                + String("windSpeed=") + data.windSpeed + ","
                + String("windDirection=") + data.windDirection;
  if (!(data.tvoc == 0 && data.eco2 == 0)) {
    lineProtocol += "," + String("tvoc=") + data.tvoc + ","
                  + String("eco2=") + data.eco2;
  }

  // Convert String to char array
  char lineProtocolChar[512];
  lineProtocol.toCharArray(lineProtocolChar, lineProtocol.length() + 1);

  // Publish MQTT Data
  if (!modem.MQTT_publish(topic.c_str(), lineProtocolChar, lineProtocol.length(), qos_level, retain_messages)) {
    printStatus("Publish failed"); 
  } else {
    printStatus("Publish successful"); 
  }

  // Close Connection (MQTT Broker & wireless)
  modem.MQTT_connect(false);
  modem.openWirelessConnection(false);
}

// GPS Functions

/**
 * Toggles the GPS module on or off.
 * @param status True to turn on the GPS, false to turn it off.
 * @return true if the GPS toggling was successful, false otherwise.
 */
bool toggleGPS(bool status) {
  // Determine the action being taken based on the status
  String action = status ? "on" : "off";

  if (!modem.enableGPS(status)) {
    printStatus(String("GPS failed to toggle ") + action);
    return false;
  } else {
    printStatus(String("GPS toggled ") + action);
    return true;
  }
}

/**
 * Queries the current GPS status from the modem and prints the result.
 * @return GPS status code
 */
int8_t getGPSStatus() {
  int8_t stat;
  printStatus("Getting GPS Status...");

  // Check GPS fix
  stat = modem.GPSstatus();
  if (stat < 0) {
    printStatus("Failed to query");
  } else if (stat == 0) {
    printStatus("GPS off");
  } else if (stat == 1) {
    printStatus("No fix");
  } else if (stat == 2) {
    printStatus("2D fix");
  } else if (stat == 3) {
    printStatus("3D fix");
  }
  return stat;
}
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

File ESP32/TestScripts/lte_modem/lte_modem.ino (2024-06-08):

/**
 * Modified example sketch to test mqtt, gps and ntp functions for the lte modem
 */

/******* ORIGINAL BOTLETICS EXAMPLE SKETCH COMMENT *******/
/*  This is an example sketch to test the core functionalities of the SIM7000/7070/7500/7600 modules.
 *  Please see the "LTE_Demo" sketch which supports many other SIMCom 2G, 3G modules; this sketch
 *  takes up less memory than the LTE_Demo sketch and is therefore suitable for microcontrollers
 *  like the ATmega32u4.
 *  
 *  Author: Timothy Woo (www.botletics.com)
 *  Github: https://github.com/botletics/SIM7000-LTE-Shield
 *  Last Updated: 11/22/2022
 *  License: GNU GPL v3.0
 */

#include "BotleticsSIM7000.h" // https://github.com/botletics/Botletics-SIM7000/tree/main/src

#define SIMCOM_7000
#define BOTLETICS_PWRKEY 18
#define RST 5
#define TX 16 // ESP32 hardware serial RX2 (GPIO16)
#define RX 17 // ESP32 hardware serial TX2 (GPIO17)

#define MQTT_SERVER      "mqtt.broker.net"
#define MQTT_PORT        1883
#define MQTT_USERNAME    "YourMQTTUsername"
#define MQTT_PASSWORD    "YourMQTTPassword"
#define MQTT_CLIENTID    "YourClientID"

// For ESP32 hardware serial
#include <HardwareSerial.h>
HardwareSerial modemSS(1);

Botletics_modem_LTE modem = Botletics_modem_LTE();

uint8_t readline(char *buff, uint8_t maxbuff, uint16_t timeout = 0);
uint8_t type;
char replybuffer[255]; // this is a large buffer for replies
char imei[16] = {0}; // MUST use a 16 character buffer for IMEI!

void setup() {
  //  while (!Serial);

  pinMode(RST, OUTPUT);
  digitalWrite(RST, HIGH); // Default state

  // Turn on the module by pulsing PWRKEY low for a little bit
  // This amount of time depends on the specific module that's used
  modem.powerOn(BOTLETICS_PWRKEY); // Power on the module

  Serial.begin(9600);
  Serial.println(F("ESP32 SIMCom Basic Test"));
  Serial.println(F("Initializing....(May take several seconds)"));

  // SIM7000 takes about 3s to turn on and SIM7500 takes about 15s
  // Press reset button if the module is still turning on and the board doesn't find it.
  // When the module is on it should communicate right after pressing reset
  
  // Start at default SIM7000 shield baud rate
  modemSS.begin(115200, SERIAL_8N1, TX, RX); // baud rate, protocol, ESP32 RX pin, ESP32 TX pin

  Serial.println(F("Configuring to 9600 baud"));
  modemSS.println("AT+IPR=9600"); // Set baud rate
  delay(100); // Short pause to let the command run
  modemSS.begin(9600, SERIAL_8N1, TX, RX); // Switch to 9600
  if (! modem.begin(modemSS)) {
    Serial.println(F("Couldn't find modem"));
    while (1); // Don't proceed if it couldn't find the device
  }

  type = modem.type();
  Serial.println(F("Modem is OK"));
  Serial.print(F("Found "));
  switch (type) {
    case SIM7000:
      Serial.println(F("SIM7000")); break;
    default:
      Serial.println(F("???")); break;
  }

  // Print module IMEI number.
  uint8_t imeiLen = modem.getIMEI(imei);
  if (imeiLen > 0) {
    Serial.print("Module IMEI: "); Serial.println(imei);
  }

  // Set modem to full functionality
  modem.setFunctionality(1); // AT+CFUN=1

  modem.setNetworkSettings(F("webLGaut")); // For HoT IoT Simcard

  printMenu();
}

void printMenu(void) {
  Serial.println(F("-------------------------------------"));
  // General
  Serial.println(F("[?] Print this menu"));

  // Time
  Serial.println(F("[y] Enable local time stamp (SIM800/808/70X0)"));
  Serial.println(F("[Y] Enable NTP time sync (SIM800/808/70X0)")); // Need to use "G" command first!
  Serial.println(F("[t] Get network time")); // Works just by being connected to network

   // MQTT
  Serial.println(F("[Q] Post via old MQTT methods"));
  Serial.println(F("[q] Post via new MQTT methods"));

  // GPS
  if (type >= SIM808_V1) {
    Serial.println(F("[O] Turn GPS on (SIM808/5320/7XX0)"));
    Serial.println(F("[o] Turn GPS off (SIM808/5320/7XX0)"));
    Serial.println(F("[x] GPS fix Status (SIM808/5320/7XX0)"));
    Serial.println(F("[L] Query GPS location (SIM808/5320/7XX0)"));
  }
  
  Serial.println(F("-------------------------------------"));
  Serial.println(F(""));
}

void loop() {
  Serial.print(F("modem> "));
  while (! Serial.available() ) {
    if (modem.available()) {
      Serial.write(modem.read());
    }
  }

  char command = Serial.read();
  Serial.println(command);


  switch (command) {
    case '?': {
        printMenu();
        break;
      }

// ===================================================================================================================

// MQTT Test

case 'Q': {       
        Serial.print(F("Connecting TCP to MQTT..."));
        
        if (!modem.TCPconnect(MQTT_SERVER, MQTT_PORT)) Serial.println(F("Failed to connect to TCP/IP!"));

        Serial.print(F("Connecting MQTT Broker..."));
        
        if (! modem.MQTTconnect("MQIsdp", MQTT_CLIENTID, MQTT_USERNAME, MQTT_PASSWORD)) Serial.println(F("Failed to connect to broker!"));
              
        // Read voltage value
        uint16_t vbat1;
        if (! modem.getBattVoltage(&vbat1)) {
          Serial.println(F("Failed to read Batt"));
        } else {
          Serial.print(F("VBat = ")); Serial.print(vbat1); Serial.println(F(" mV"));
        }

        char battBuff[12];
        dtostrf(vbat1, 1, 0, battBuff);
        
        // Publish message
        if (! modem.MQTTpublish("voltage", battBuff)) Serial.println(F("Failed to publish!"));

        modem.MQTTdisconnect();
        modem.TCPclose();

        break;
}
 
// MQTT Test2

case 'q': {       
        Serial.print(F("Connecting to MQTT Broker..."));
        

        modem.openWirelessConnection(true);

        // Set up MQTT parameters (see MQTT app note for explanation of parameter values)
        modem.MQTT_setParameter("URL", MQTT_SERVER, MQTT_PORT);
        // Set up MQTT username and password if necessary
        modem.MQTT_setParameter("USERNAME", MQTT_USERNAME);
        modem.MQTT_setParameter("PASSWORD", MQTT_PASSWORD);
        modem.MQTT_setParameter("CLIENTID", MQTT_CLIENTID);
        
    
        Serial.println(F("Connecting to MQTT broker..."));
        if (! modem.MQTT_connect(true)) Serial.println(F("Failed to connect to broker!"));
      
        // Read voltage value
        uint16_t vbat1;
        if (! modem.getBattVoltage(&vbat1)) {
          Serial.println(F("Failed to read Batt"));
        } else {
          Serial.print(F("VBat = ")); Serial.print(vbat1); Serial.println(F(" mV"));
        }

        char battBuff[12];
        dtostrf(vbat1, 1, 0, battBuff);

        if (!modem.MQTT_publish("voltage2", battBuff, strlen(battBuff), 1, 0)) Serial.println(F("Failed to publish!")); 
  
        modem.MQTT_connect(false);
        modem.openWirelessConnection(false);

        break;
}
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

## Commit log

2023-05-03 SensorList changed
2023-05-04 Changed SensorList
2023-05-04 Changed SQLInsert and added all Sensor info
2023-05-08 Update ReadSensors.ino
    Changed Sensor
2023-05-11 Link to Home button added
2023-05-17 Update MainScript.ino
    Added the MySQL query to send Sensor Data
2023-06-04 Added 3D Models
    [uWeatherBoxBottom.stl, uWeatherBoxMiddle.stl, uWeatherBoxTop.stl]
2024-05-08 Update MainScript.ino
    Fixed Issue
    [MainScript.ino]
2024-05-15 Update MainScript.ino
    Added KY-003 Digital Hall Sensor (Anemometer)
2024-05-15 Update MainScript.ino
    Fixed several Issues (executable)
    [MainScript.ino]
2024-05-16 Update MainScript.ino
    Added Rotary Hall Sensor (Wind-Vane) & Set m/s to km/h (Anemometer)
2024-06-01 Update MainScript.ino
    Added LTE module & fixes/updates
    [MainScript.ino]
2024-06-02 Update MainScript.ino
    Added SensorData struct & Modified functions
2024-06-02 Update MainScript.ino
    Fixed Issues
    [MainScript.ino]
2024-06-02 Update MainScript.ino
    Modified printOledLine function
2024-06-08 Update sensor_hall.ino & sensor_sgp30.ino
    Changed Comments
2024-06-08 Update sensor_multi.ino & Removed sensor_rain.ino
    Merged scripts
2024-06-08 Update MainScript.ino
    Improved code & Fixed several issues (executable)
    [MainScript.ino]
2024-06-15 Update ESP32 Documentation
2024-08-01 Renamed Folder
    [uWeatherBoxBottom.stl, uWeatherBoxMiddle.stl, uWeatherBoxTop.stl]
2024-08-01 Added 3D models (.stl)
    [Anemometer_Body.stl, Anemometer_Cap.stl, Anemometer_Cup.stl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]
